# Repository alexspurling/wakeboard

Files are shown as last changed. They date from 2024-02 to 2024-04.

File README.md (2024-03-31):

# Wakeboard

A custom Kicad PCB based on the ESP32 and LIS3DH accelerometer. I built this to use as a low power device to detect when my washing machine starts and to send me a notification when it ends.

All files are open source under the Apache Licence 2.0

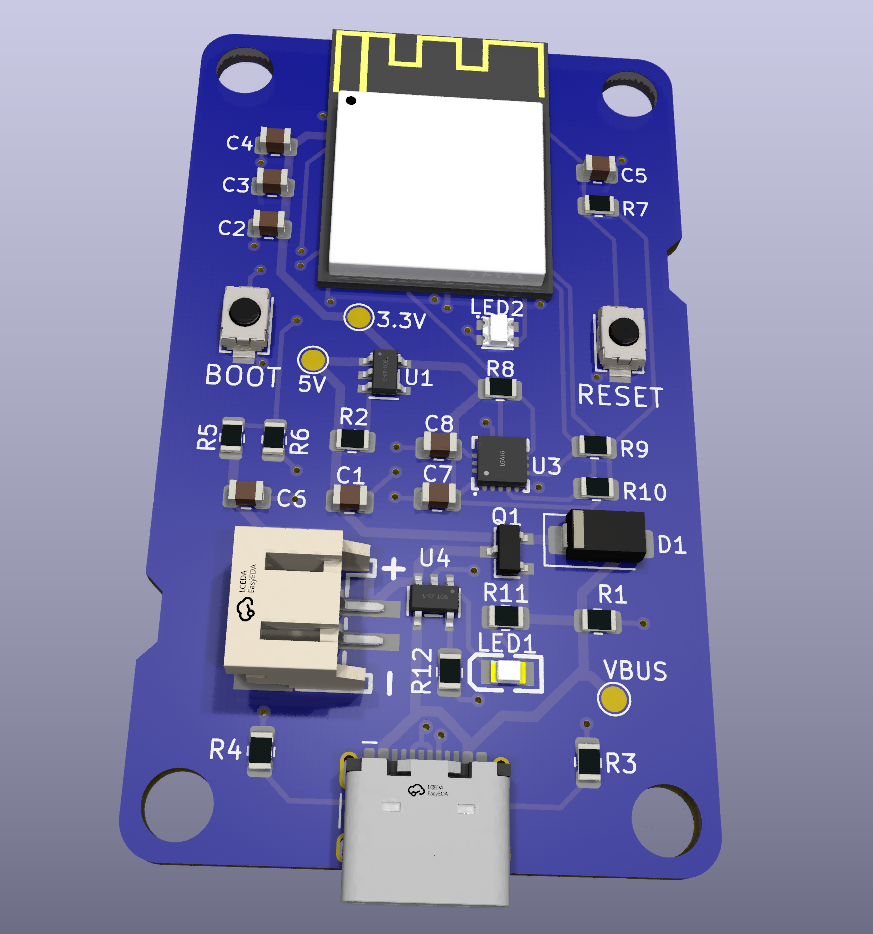
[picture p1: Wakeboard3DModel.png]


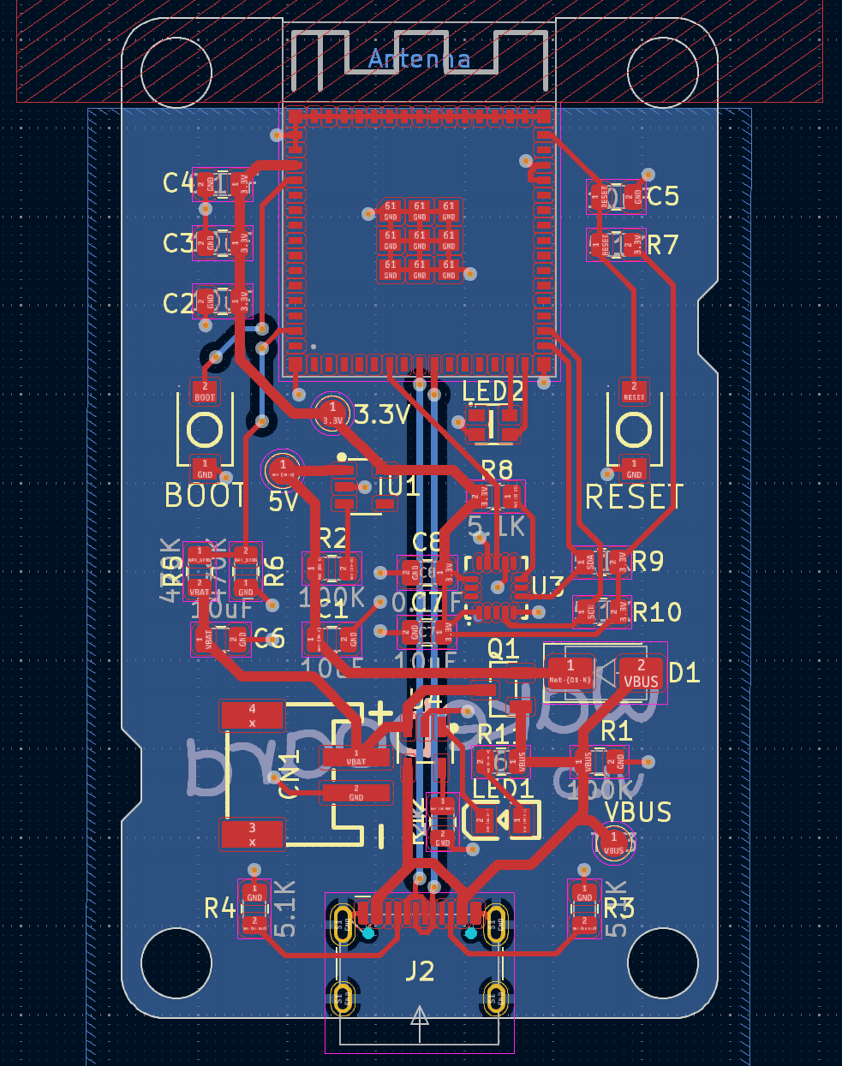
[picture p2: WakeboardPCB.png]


WakeboardSchema.pdf

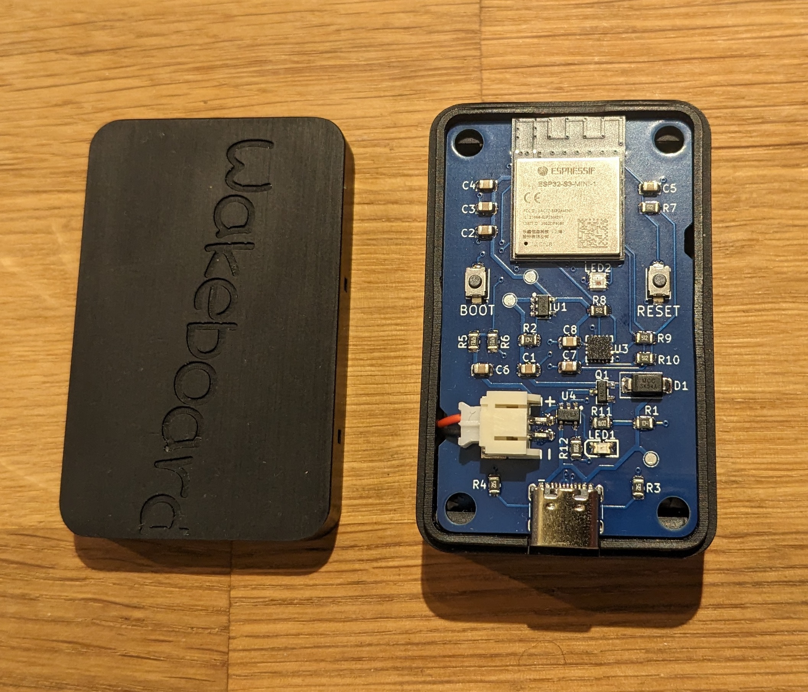
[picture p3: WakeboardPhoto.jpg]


## Instructions for adding components

Since I wanted to order the PCB with JLCPCB, I wanted to ensure I picked parts that they have in stock. To do this, I used [easyeda2kicad](https://github.com/uPesy/easyeda2kicad.py) to pull the schematic, footprint and 3D model of a given LCSC part number. To run the script:

```
pip install easyeda2kicad
```

```
easyeda2kicad --full --lcsc_id=C2894897
```

This will copy files from EasyEDA (JLCPCB's own PCB creation tool) and save them into your `Documents/Kicad` directory.

From here, you can add this location as a library into KiCad to make all your downloaded components available:

* In KiCad, Go to Preferences > Configure Paths, and add the environment variables EASYEDA2KICAD :

    Windows : C:/Users/your_username/Documents/Kicad/easyeda2kicad/,
    Linux : /home/your_username/Documents/Kicad/easyeda2kicad/

* Go to Preferences > Manage Symbol Libraries, and Add the global library easyeda2kicad : ${EASYEDA2KICAD}/easyeda2kicad.kicad_sym
* Go to Preferences > Manage Footprint Libraries, and Add the global library easyeda2kicad : ${EASYEDA2KICAD}/easyeda2kicad.pretty

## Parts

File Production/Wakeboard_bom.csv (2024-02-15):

Reference | Value | Footprint | Qty | LCSC Part
C1,C2,C3,C5,C6,C7 | 10uF | Capacitor_SMD:C_0805_2012Metric | 6 | C1713
C4,C8 | 0.1uF | Capacitor_SMD:C_0805_2012Metric | 2 | C1711
CN1 | JST S2B-PH-SM4-TB(LF)(SN) | easyeda2kicad:CONN-SMD_P2.00_S2B-PH-SM4-TB-LF-SN | 1 | C295747
D1 | SK54A-LTP | Diode_SMD:D_SMA | 1 | C669017
J2 | HCTL HC-TYPE-C-16P-01A | Connector_USB:USB_C_Receptacle_HCTL_HC-TYPE-C-16P-01A | 1 | C2894897
LED1 | FC-2012HRK-620D | easyeda2kicad:LED0805-R-RD | 1 | C84256
LED2 | WS2812B-2020 | easyeda2kicad:LED-SMD_4P-L2.0-W2.0-TL_WS2812B-2020 | 1 | C965555
Q1 | DMP2045UQ-7 | easyeda2kicad:SOT-23-3_L2.9-W1.3-P0.95-LS2.4-BR | 1 | C5157511
R1,R2 | 100K | Resistor_SMD:R_0805_2012Metric | 2 | C25611
R3,R4,R7,R8,R9,R10 | 5.1K | Resistor_SMD:R_0805_2012Metric | 6 | C26023
R5,R6 | 470K | Resistor_SMD:R_0805_2012Metric | 2 | C17709
R11 | 160 | Resistor_SMD:R_0805_2012Metric | 1 | C25269
R12 | 2k | Resistor_SMD:R_0805_2012Metric | 1 | C17604
SW1,SW2 | TS-1088-AR02016 | easyeda2kicad:SW-SMD_L3.9-W3.0-P4.45 | 2 | C720477
U1 | RT9080-33GJ5 | easyeda2kicad:TSOT-23-5_L2.9-W1.6-P0.95-LS2.8-BL | 1 | C841192
U2 | ESP32-S3-MINI-1 | RF_Module:ESP32-S2-MINI-1 | 1 | C2913206
U3 | LIS3DHTR_C15134 | easyeda2kicad:LGA-16_L3.0-W3.0-P0.50-TL | 1 | C15134
U4 | MCP73831T-2ACI/OT | easyeda2kicad:SOT-23-5_L3.0-W1.7-P0.95-LS2.8-BL | 1 | C424093

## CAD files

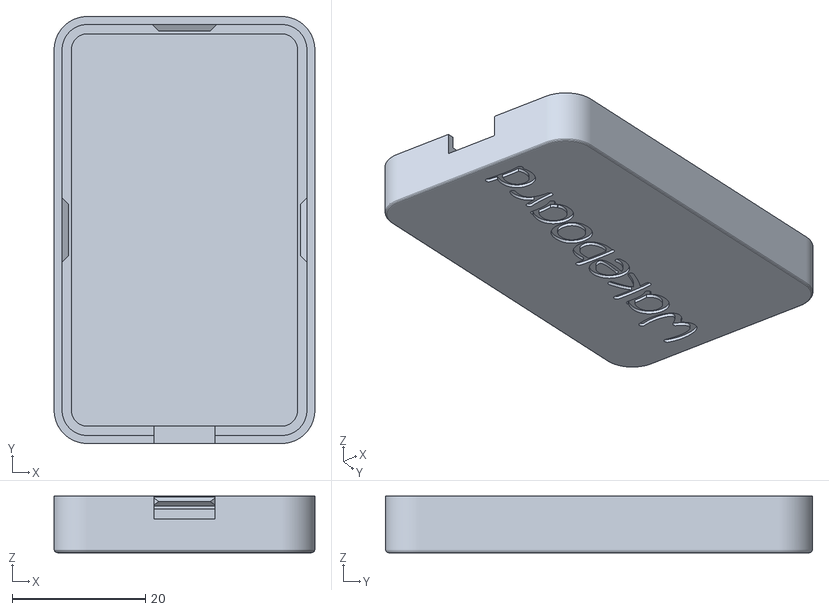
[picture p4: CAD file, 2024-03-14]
Enclosure/WakeboardLid.stl
39.2 x 64.2 x 8.50

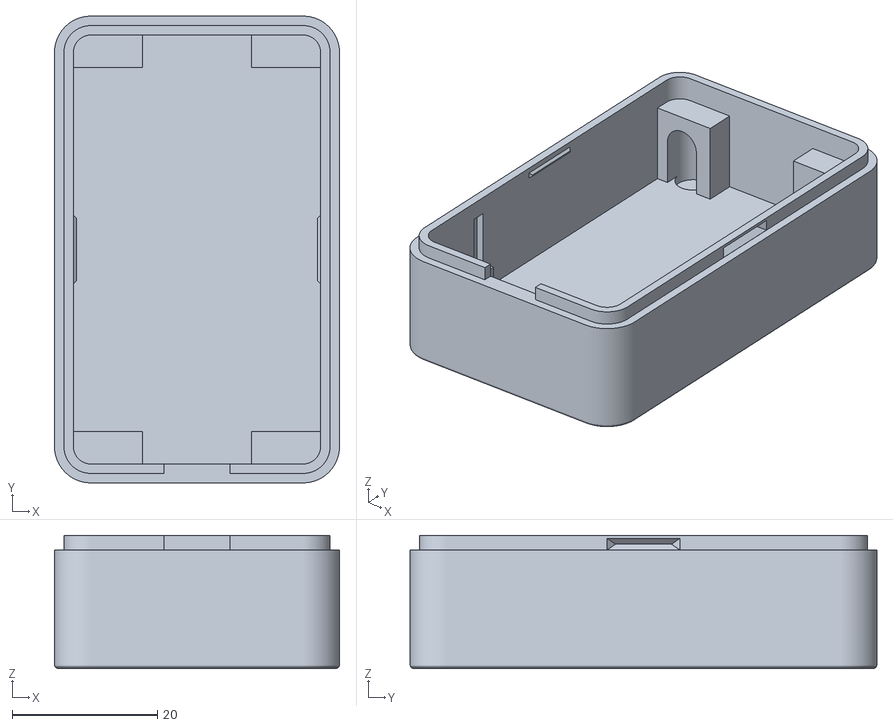
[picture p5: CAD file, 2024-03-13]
Enclosure/WakeboardBase.stl
39.2 x 64.2 x 18.3

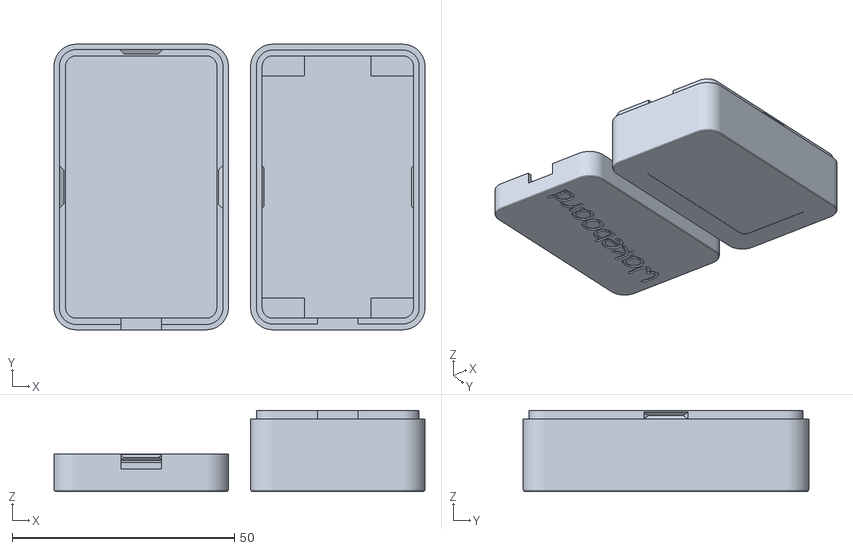
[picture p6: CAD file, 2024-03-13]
Enclosure/Wakeboard.stl
83.4 x 64.2 x 18.3

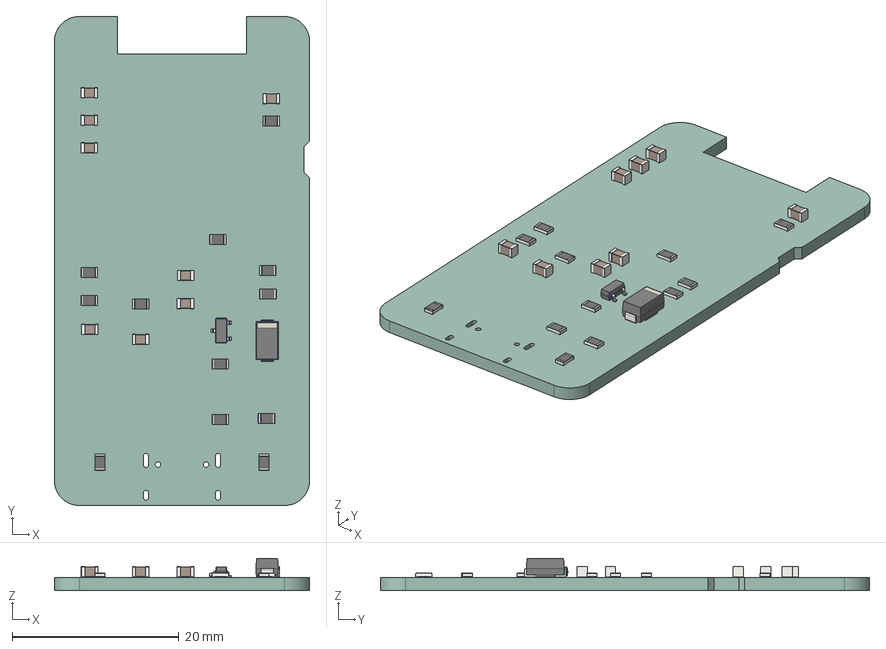
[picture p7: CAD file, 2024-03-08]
Enclosure/WakeboardPCB.step
30.6 x 58.6 x 3.85 mm
R_0805_2012Metric x 12
SOT_23
C_0805_2012Metric x 8
D_SMA
Wakeboard_PCB

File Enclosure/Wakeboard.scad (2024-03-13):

use <MCAD/boxes.scad>
$fa=1;
$fs=0.2;


inner_width = 34;
inner_length = 59;
inner_height = 13.2;

pcb_width = 30.6;
pcb_length = 58.6;
pcb_height = 1.6;

battery_width = 34.6;
battery_length = 49.6;
battery_height = 11.3;

wall_thickness = 2.6;

outer_width = inner_width + wall_thickness * 2;
outer_length = inner_length + wall_thickness * 2;
outer_height = inner_height + wall_thickness;

outer_radius = 5;
bevel_radius = 0.5;

base = wall_thickness + bevel_radius;

lip_thickness = 1.3;
lip_height = 2;

support_width = 9.5;
support_height = 11.6;
support_radius = 4.5;

magnet_radius = 2.5;
magnet_height = 4;

battery_socket_width = 7.4;
battery_socket_length = 7.9;
battery_socket_height = 5.5;

battery_socket_x = (outer_width / 2 - pcb_width / 2) + 4.8;
battery_socket_y = (outer_length / 2 - pcb_length / 2) + 9;

slot_depth = 1;
slot_width = 2;
slot_height = support_height + 1;

lid_height = 8;
lid_inner_height = lid_height - wall_thickness;

usb_hole_width = 9.1;
usb_hole_height = 3.5;

tab_width = 10;
tab_height = lip_height - 0.4;


module roundedBox(w, l, h, r) {
    translate([r, r, 0]) cylinder(h, r, r);
    translate([w - r, r, 0]) cylinder(h, r, r);
    translate([w - r, l - r, 0]) cylinder(h, r, r);
    translate([r, l - r, 0]) cylinder(h, r, r);
    
    translate([0, r, 0])
    cube([w, l - 2 * r, h]);
    
    translate([r, 0, 0])
    cube([w - 2 * r, l, h]);
}

module box(w, l, h, r, br=0) {
    if (br > 0) {
        hull() {
            translate([r, r, br])
            rotate_extrude(angle=90, convexity=2)
            translate([-r + br, 0]) circle(br);

            translate([w - r, r, br])
            rotate([0, 0, 90])
            rotate_extrude(angle=90, convexity=2)
            translate([-r + br, 0]) circle(br);

            translate([w - r, l - r, br])
            rotate_extrude(angle=90, convexity=2)
            translate([r - br, 0]) circle(br);

            translate([r, l - r, br])
            rotate([0, 0, 90])
            rotate_extrude(angle=90, convexity=2)
            translate([r - br, 0]) circle(br);
        }
    }

    translate([0, 0, br])
    roundedBox(w, l, h, r);
}

module box_with_lip(inner_width, inner_length, inner_height, radius, wall_thickness, bevel_radius) {
    
    outer_width = inner_width + wall_thickness * 2;
    outer_length = inner_length + wall_thickness * 2;
    outer_height = inner_height + wall_thickness;
    
    difference() {
        // outer box
        union() {
            box(outer_width, outer_length, outer_height, radius, bevel_radius);
            // lip
            translate([wall_thickness - lip_thickness, wall_thickness - lip_thickness, outer_height + bevel_radius])
            box(inner_width + lip_thickness * 2, inner_length + lip_thickness * 2, lip_height, radius - wall_thickness + lip_thickness, 0);
        }
        
        // inner cutout
        translate([wall_thickness, wall_thickness, base])
        box(inner_width, inner_length, outer_height + 0.1, radius - wall_thickness, 0);
        
        recess_width = outer_width - 15;
        recess_length = outer_length - 15;
        recess_height = 0.15;
        recess_radius = 2;
        // bottom recess
        translate([outer_width / 2 - recess_width / 2, outer_length / 2 - recess_length / 2, -0.05])
        box(recess_width, recess_length, recess_height, recess_radius, 0);
        
        // cutout for tab slot left
        translate([wall_thickness - lip_thickness -0.05, outer_length / 2 - tab_width / 2, outer_height + bevel_radius])
        cube([lip_thickness + 0.1, tab_width, lip_height]);
        
        // cutout for tab slot right
        translate([outer_width - wall_thickness -0.05, outer_length / 2 - tab_width / 2, outer_height + bevel_radius])
        cube([lip_thickness + 0.1, tab_width, lip_height]);
        
        // cutout for tab slot back
        translate([outer_width / 2 - tab_width / 2, outer_length - wall_thickness - 0.05, outer_height + bevel_radius])
        cube([tab_width, lip_thickness + 0.1, lip_height]);
    }
    
    // tab slot left
    translate([wall_thickness - lip_thickness, outer_length / 2 + tab_width / 2, outer_height + bevel_radius])
    rotate([0, 0, 270])
    tab_slot(tab_width, tab_height);
    
    // tab slot right
    translate([outer_width - wall_thickness + lip_thickness, outer_length / 2 - tab_width / 2, outer_height + bevel_radius])
    rotate([0, 0, 90])
    tab_slot(tab_width, tab_height);
    
    // tab slot back
    translate([outer_width / 2 + tab_width / 2, outer_length - wall_thickness + lip_thickness, outer_height + bevel_radius])
    rotate([0, 0, 180])
    tab_slot(tab_width, tab_height, 0);
    
    supports();
}

module usb_hole(xpos, ypos, zpos) {
    translate([xpos - usb_hole_width / 2, ypos, zpos])
    cube([usb_hole_width, 5, usb_hole_height]);
}

module fillet(radius, height) {
    linear_extrude(height=height)
    difference() {
        square([radius, radius]);
        translate([radius, radius])
        circle(radius);
    }
}

module support(radius, width, height) {
    r2 = radius / 2;
    rotate([0, 0, 90])
    fillet(r2, height);
    translate([width, 0])
    fillet(r2, height);
    
    hull() {
        translate([r2, r2])
        cylinder(height, r2, r2);
        
        translate([width-r2, r2])
        cylinder(height, r2, r2);
        
        cube([width, r2, height]);
    }
}

/*
module supports() {
    translate([outer_width - 10, wall_thickness, base])
    support(support_radius, support_width, support_height);

    translate([outer_width / 2 + (support_width / 2), wall_thickness + inner_length, base])
    rotate([0, 0, 180])
    support(support_radius, support_width, support_height);
}
*/

module supports() {
    translate([wall_thickness, wall_thickness, base])
    cube([support_width, support_radius, support_height]);
    
    translate([outer_width - wall_thickness - support_width, wall_thickness, base])
    cube([support_width, support_radius, support_height]);
    
    translate([wall_thickness, outer_length - wall_thickness - support_radius, base])
    cube([support_width, support_radius, support_height]);
    
    translate([outer_width - wall_thickness - support_width, outer_length - wall_thickness - support_radius, base])
    cube([support_width, support_radius, support_height]);
}

module battery() {
    color([0.5, 0.5, 0.5, 0.9])
    translate([wall_thickness + 0.2, wall_thickness + support_radius + 0.2, base])
    cube([battery_width, battery_length, battery_height]);
}


module magnet_hole() {
    mhr = magnet_radius + 0.1; // magnet hole radius
    h = magnet_height * 2;
    xoffset = 2;
    yoffset = -0.5;
    
    translate([0, 0, -lip_thickness])
    cylinder(h, mhr, mhr);
    translate([0, 0, h - lip_thickness])
    sphere(mhr);
    translate([0, 0, h - lip_thickness])
    rotate([90, 0, 0])
    cylinder(mhr * 1.5, mhr, mhr);
    translate([-mhr, -mhr * 1.5, 0])
    cube([mhr * 2, mhr * 1.5, h - lip_thickness]);
}


module magnet_holes() {
    mhr = magnet_radius + 0.1; // magnet hole radius
    h = magnet_height * 2;
    xoffset = 2;
    yoffset = -0.5;
    
    translate([outer_radius + xoffset, outer_radius + yoffset, base])
    rotate([0, 0, 180])
    magnet_hole();
    
    translate([outer_width - outer_radius - xoffset, outer_radius + yoffset, base])
    rotate([0, 0, 180])
    magnet_hole();
    
    translate([outer_radius + xoffset, outer_length - outer_radius - yoffset, base])
    magnet_hole();
    
    translate([outer_width - outer_radius - xoffset, outer_length - outer_radius - yoffset, base])
    magnet_hole();
}

module battery_wire_slot() {
    translate([wall_thickness - slot_depth, battery_socket_y + battery_socket_length / 2 - slot_width / 2, base])
    cube([slot_depth + 0.2, slot_width, slot_height]);
}


module case() {
    difference () {
        box_with_lip(inner_width, inner_length, inner_height, outer_radius, wall_thickness, bevel_radius);
        usb_hole(outer_width / 2, 0, inner_height + base + 0.01);
        magnet_holes();
        battery_wire_slot();
    }
    mhr = magnet_radius + 0.1; // magnet hole radius
    h = magnet_height * 1.5;
    xoffset = 2;
    yoffset = -0.5;
}
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

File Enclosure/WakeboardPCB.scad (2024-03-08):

// CSG file generated from FreeCAD 0.21.2
group() {
 group(){
}
}

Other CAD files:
Enclosure/WakeboardBase.scad
Enclosure/WakeboardLid.scad
Enclosure/WakeboardPCB.stl

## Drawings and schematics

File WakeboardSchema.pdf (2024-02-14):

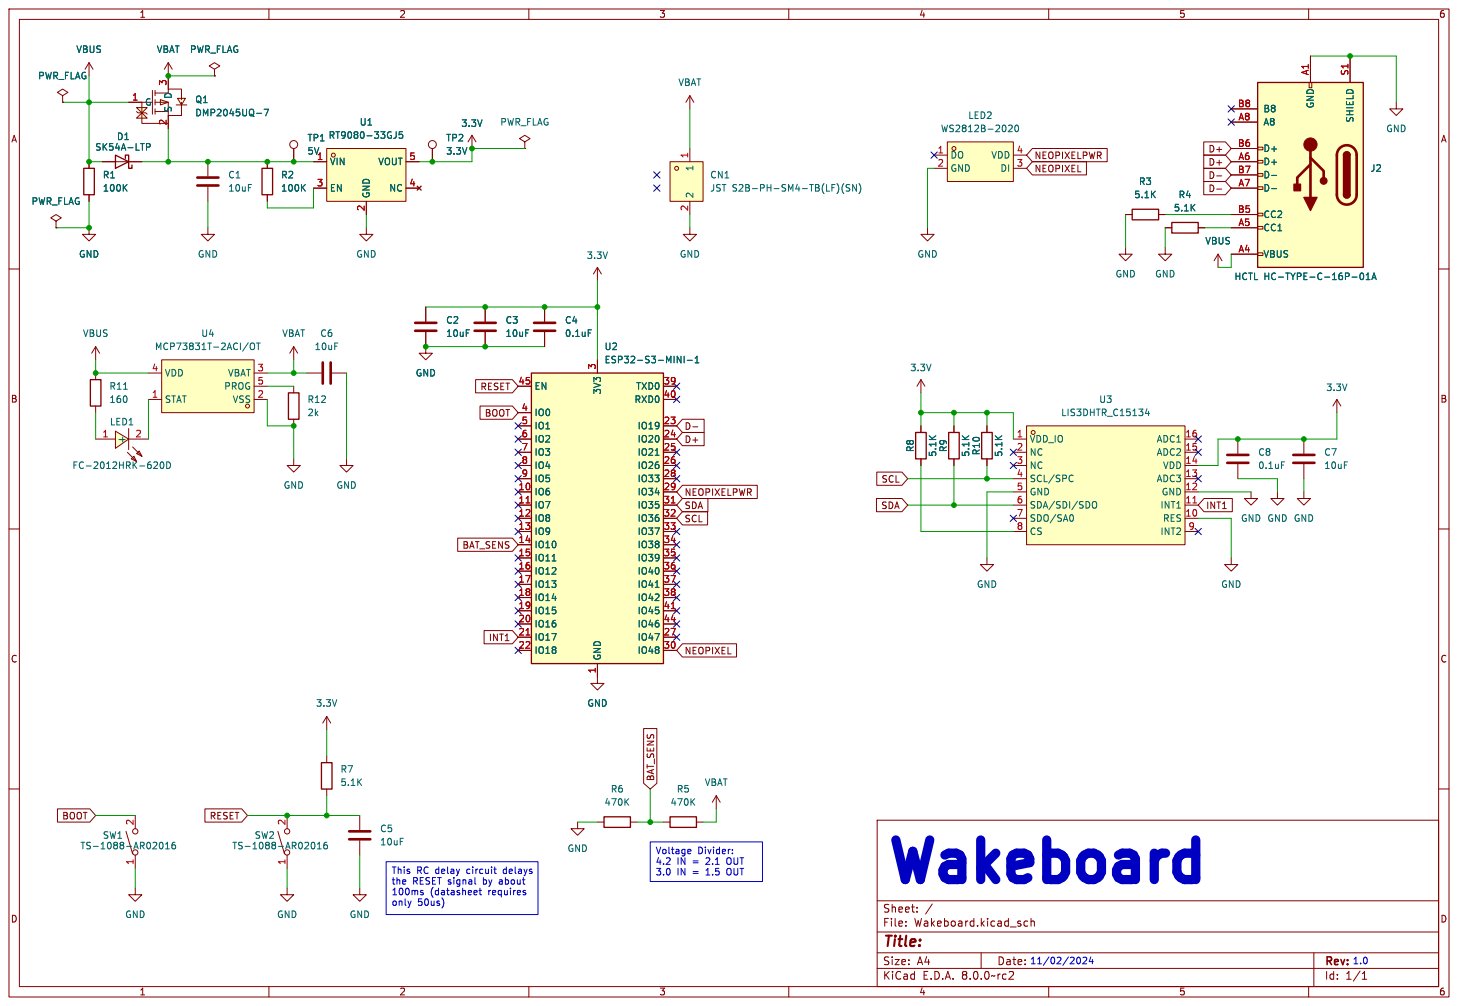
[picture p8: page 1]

INT1 11 GND 12 ADC3 13 VDD 14 ADC2 15 ADC1 16 NC 2 NC 3 SCL/SPC 4 GND 5 SDA/SDI/SDO 6 SDO/SA0 7 CS 8

Id: 1/1 Title: File: Wakeboard.kicad_sch Sheet: /

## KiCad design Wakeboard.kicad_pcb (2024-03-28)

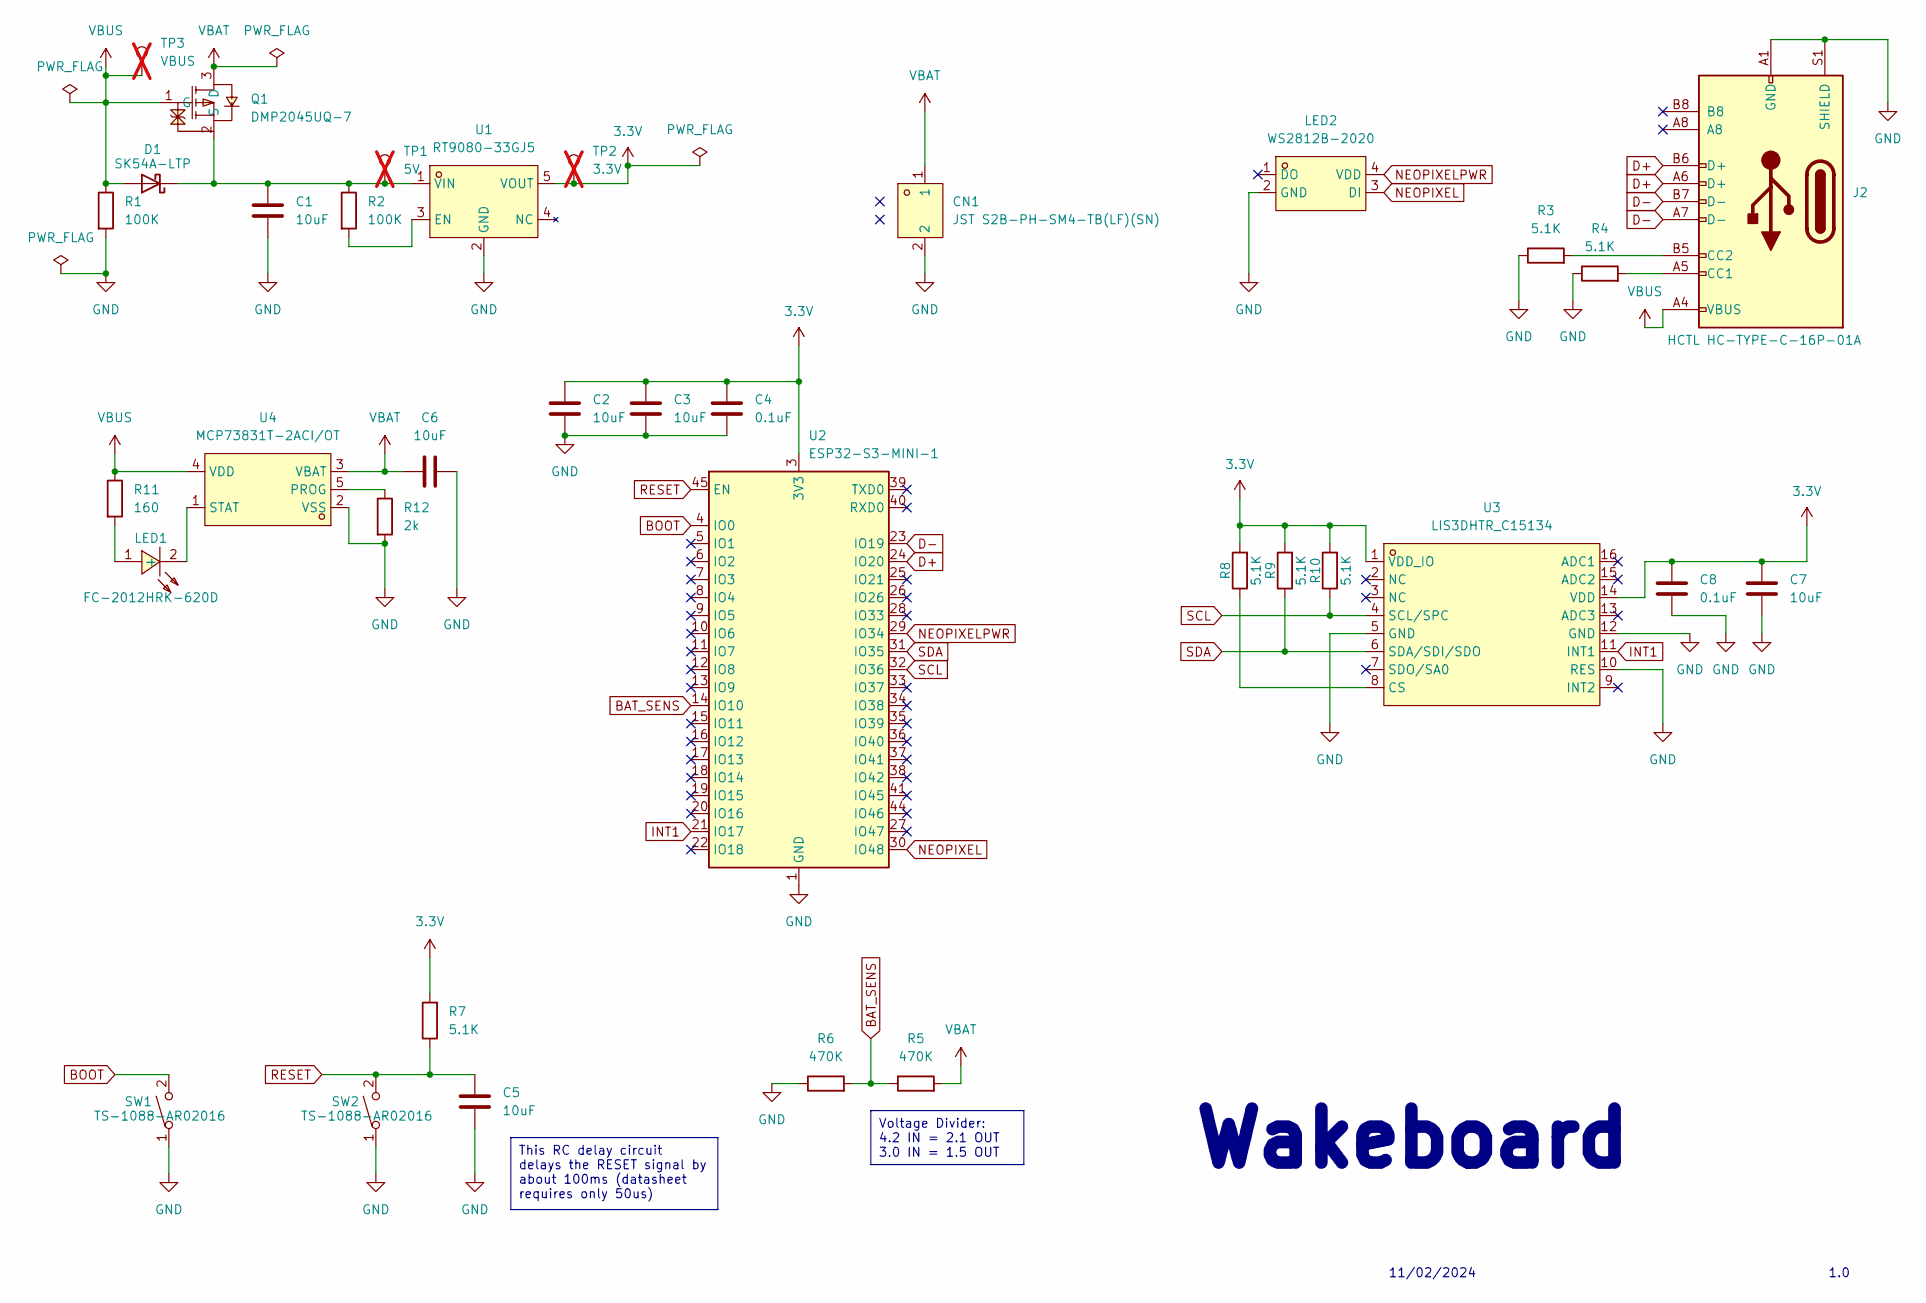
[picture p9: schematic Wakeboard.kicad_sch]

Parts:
C1, C2, C3, C5, C6, C7: 10uF; C_0805_2012Metric; LCSC Part C1713
C4, C8: 0.1uF; C_0805_2012Metric; LCSC Part C1711
CN1: JST S2B-PH-SM4-TB(LF)(SN); CONN-SMD_P2.00_S2B-PH-SM4-TB-LF-SN; LCSC Part C295747
D1: SK54A-LTP; D_SMA; LCSC Part C669017
J2: HCTL HC-TYPE-C-16P-01A; USB_C_Receptacle_HCTL_HC-TYPE-C-16P-01A; LCSC Part C2894897
LED1: FC-2012HRK-620D; LED0805-R-RD; LCSC Part C84256
LED2: WS2812B-2020; LED-SMD_4P-L2.0-W2.0-TL_WS2812B-2020; LCSC Part C965555
Q1: DMP2045UQ-7; SOT-23-3_L2.9-W1.3-P0.95-LS2.4-BR; LCSC Part C5157511
R1, R2: 100K; R_0805_2012Metric; LCSC Part C25611
R3, R4, R7, R8, R9, R10: 5.1K; R_0805_2012Metric; LCSC Part C26023
R5, R6: 470K; R_0805_2012Metric; LCSC Part C17709
R11: 160; R_0805_2012Metric; LCSC Part C25269
R12: 2k; R_0805_2012Metric; LCSC Part C17604
SW1, SW2: TS-1088-AR02016; SW-SMD_L3.9-W3.0-P4.45; LCSC Part C720477
TP1: 5V; TestPoint_Pad_D1.5mm; not fitted
TP2: 3.3V; TestPoint_Pad_D1.5mm; not fitted
TP3: VBUS; TestPoint_Pad_D1.5mm; not fitted
U1: RT9080-33GJ5; TSOT-23-5_L2.9-W1.6-P0.95-LS2.8-BL; LCSC Part C841192
U2: ESP32-S3-MINI-1; ESP32-S2-MINI-1; LCSC Part C2913206
U3: LIS3DHTR_C15134; LGA-16_L3.0-W3.0-P0.50-TL; LCSC Part C15134
U4: MCP73831T-2ACI/OT; SOT-23-5_L3.0-W1.7-P0.95-LS2.8-BL; LCSC Part C424093

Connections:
3.3V: C2.1, C3.1, C4.1, C7.1, C8.1, R7.2, R8.2, R9.2, R10.2, TP2.1, U1.5 (VOUT), U2.3 (3V3), U3.1 (VDD_IO), U3.14 (VDD)
BAT_SENS: R5.1, R6.2, U2.14 (IO10)
BOOT: SW1.2, U2.4 (IO0)
D+: J2.A6 (D+), J2.B6 (D+), U2.24 (IO20)
D-: J2.A7 (D-), J2.B7 (D-), U2.23 (IO19)
GND: C1.2, C2.2, C3.2, C4.2, C5.2, C6.2, C7.2, C8.2, CN1.2, J2.A1 (GND), J2.A12 (GND), J2.B1 (GND), J2.B12 (GND), J2.S1 (SHIELD), LED2.2 (GND), R1.2, R3.1, R4.1, R6.1, R12.2, SW1.1, SW2.1, U1.2 (GND), U2.1 (GND), U2.2 (GND), U2.42 (GND), U2.43 (GND), U2.46 (GND), U2.47 (GND), U2.48 (GND), U2.49 (GND), U2.50 (GND), U2.51 (GND), U2.52 (GND), U2.53 (GND), U2.54 (GND), U2.55 (GND), U2.56 (GND), U2.57 (GND), U2.58 (GND), U2.59 (GND), U2.60 (GND), U2.61 (GND), U2.62 (GND), U2.63 (GND), U2.64 (GND), U2.65 (GND), U3.5 (GND), U3.10 (RES), U3.12 (GND), U4.2 (VSS)
INT1: U2.21 (IO17), U3.11 (INT1)
NEOPIXEL: LED2.3 (DI), U2.30 (IO48)
NEOPIXELPWR: LED2.4 (VDD), U2.29 (IO34)
unnamed: C1.1, D1.1 (K), Q1.2 (S), R2.1, TP1.1, U1.1 (VIN)
unnamed: J2.A5 (CC1), R4.2
unnamed: J2.B5 (CC2), R3.2
unnamed: LED1.1 (+), R11.2
unnamed: LED1.2 (-), U4.1 (STAT)
unnamed: R2.2, U1.3 (EN)
unnamed: R8.1, U3.8 (CS)
unnamed: R12.1, U4.5 (PROG)
RESET: C5.1, R7.1, SW2.2, U2.45 (EN)
SCL: R10.1, U2.32 (IO36), U3.4 (SCL/SPC)
SDA: R9.1, U2.31 (IO35), U3.6 (SDA/SDI/SDO)
VBAT: C6.1, CN1.1, Q1.3 (D), R5.2, U4.3 (VBAT)
VBUS: D1.2 (A), J2.A4 (VBUS), J2.A9 (VBUS), J2.B4 (VBUS), J2.B9 (VBUS), Q1.1 (G), R1.1, R11.1, TP3.1, U4.4 (VDD)

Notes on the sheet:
This RC delay circuit delays the RESET signal by about 100ms (datasheet requires only 50us)
Voltage Divider: 4.2 IN = 2.1 OUT 3.0 IN = 1.5 OUT
1.0
11/02/2024
Wakeboard

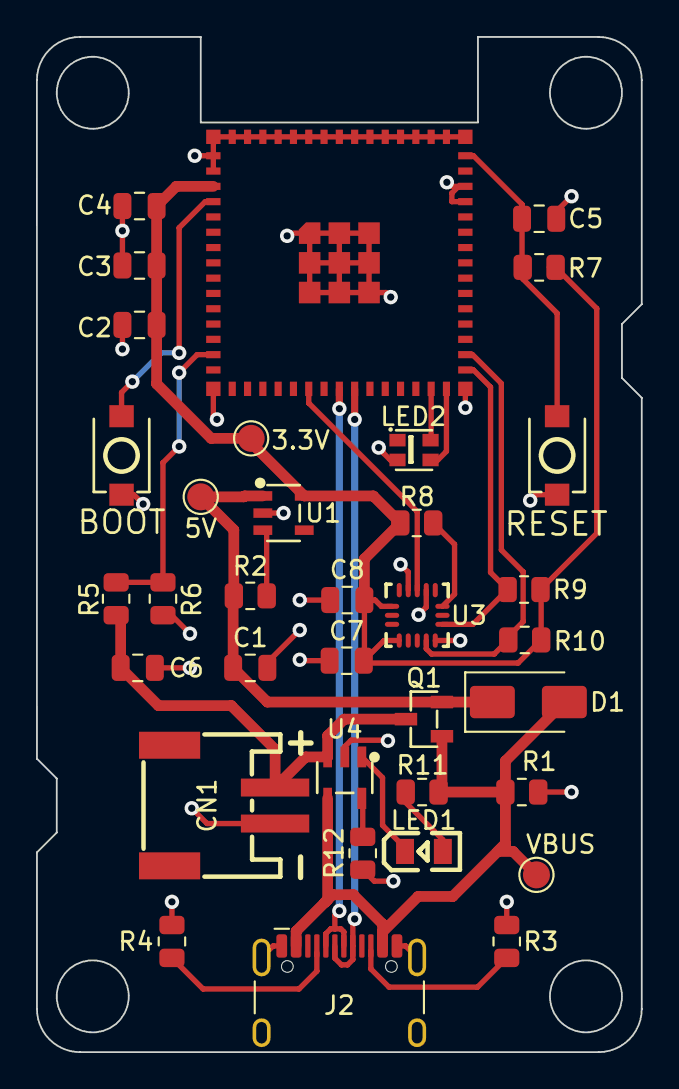
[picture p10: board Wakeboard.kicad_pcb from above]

Board: 2 copper layers, 33.6 x 56.4 mm, 35 parts (0 on the bottom side), 22 nets.

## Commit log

2024-02-12 PCB Layout
    [Washingboard.kicad_pcb, Washingboard.kicad_sch]
2024-02-14 PCB and Schematic v1.0
    [Wakeboard.kicad_pcb, Wakeboard.kicad_sch, Washingboard.kicad_pcb]
2024-02-14 Remove PCB below antenna. Swap SDA and SCL GPIO. Update interrupt to GPIO 21, battery level to GPIO 10.
    [Wakeboard.kicad_pcb, Wakeboard.kicad_sch]
2024-02-14 Small update to PCB
    [Wakeboard.kicad_pcb]
2024-02-15 Adding Gerber and BOM files
    [Wakeboard-B_Cu.gbl, Wakeboard-B_Mask.gbs, Wakeboard-B_Paste.gbp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]
2024-03-06 Shift battery socket
    [Wakeboard.kicad_pcb]
2024-03-07 Remove mounting holes. Fix minor things
    [Wakeboard.kicad_pcb]
2024-03-07 Enclosure OpenSCAD files
    [Wakeboard.kicad_pcb, Wakeboard.scad]
2024-03-07 Add USB hole
    [Wakeboard.scad]
2024-03-07 Add supports. Set wall thickness to 2.6
    [Wakeboard.scad, Wakeboard.stl]
2024-03-08 Add magnet holes. Add battery and PCB templates
    [Wakeboard.scad, WakeboardPCB.amf, WakeboardPCB.scad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]
2024-03-12 Enclosure with lid
    [Wakeboard.scad]
2024-03-13 Snapfit lid
    [Wakeboard.scad]
2024-03-13 Small recess on the base
    [Wakeboard.scad]
2024-03-13 Export STL
    [Wakeboard.stl]
2024-03-13 Split into base and lid
    [WakeboardBase.scad, WakeboardBase.stl, WakeboardLid.scad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]
2024-03-14 Add cut outs to view LEDs
    [WakeboardLid.scad, WakeboardLid.stl]
2024-03-15 Resize board
    [Wakeboard.kicad_pcb]
2024-03-15 Shift components after resize
    [Wakeboard.kicad_pcb, Wakeboard.kicad_sch]
2024-03-28 Production files for latest PCB
    [Wakeboard-B_Cu.gbl, Wakeboard-B_Mask.gbs, Wakeboard-B_Paste.gbp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]
2024-03-31 Update 3D render
    [WakeboardPCB.amf]
2024-04-01 Update PCB image
